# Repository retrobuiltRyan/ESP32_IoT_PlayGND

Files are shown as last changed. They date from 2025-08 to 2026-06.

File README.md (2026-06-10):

# ESP32_IoT_PlayGND
Internet of Things + MQTT sensor, input, actuator, motor drive learning board. Can be powered with a power drill battery for immediate remote deployment and sensor monitoring.

Learning Goal: Quick start "how to" develop and build your own IIoT solution with scale and affordability in mind using off-the-shelf hardware and lightweight software.

# Hardware Rev 1.0

| Category | Components |
|---|---|
| **Microcontroller** | ESP32-WROOM-32 |
| **Sensors/Input** | - Temperature & Humidity (SHT45) <br> - Voltage, Current, Power (INA260) <br> - Pushbutton (x4) <br> - Rotary Encoder |
| **Actuators** | - Relay (10A, 277VAC, 30VDC) <br> - DRV8871 (DC Motor Drive) <br> - A4988 (Stepper Motor Drive) <br> - 4 CH Servo (PCA9685) |
| **Output** | - RGB LED (x4) <br> - OLED (128x64 pixel) <br> - Buzzer |

IoT PlayGND pic
3D render

ESP-WROOM-32 ESP32: https://www.amazon.com/gp/product/B0D8Q8XFRK/ <br>
USB Drivers for FTDI chips https://docs.espressif.com/projects/esp-idf/en/stable/esp32/get-started/establish-serial-connection.html

BoM
## Bill of Materials (BOM)
| Reference | Value | Qty | DigiKey P/N | Adafruit P/N | AliExpress / Amazon Link |
|---|---|-----|---|---|---|
| BZ1 | Buzzer_5V | 1 | 445-2525-1-ND | | |
| C3, C4, C7 | 0.1uF 50V | 3 | 1276-1068-1-ND | | |
| C10, C11 | 0.22uF 50V CER | 2 | 445-2283-1-ND | | |
| C12, C13, C14 | 22uF 50V | 3 | 399-11438-1-ND | | |
| D2 | D | 1 | S5AC-FDICT-ND | | |
| D3, D6, D7, D8 | WS2812B | 4 |1568-16347CT-ND | |[Aliexpress Link](https://www.aliexpress.us/item/3256802466699315.html) |
| D5, D9, D11, D13 | LED, Green | 3 |1080-1419-1-ND | | |
| D10 | LED Red, 5mm | 1 | EALP05RDHRA2-ND | | |
| D12 | SMF15A | 1 | SMF15A-E3-08CT-ND | | |
| D14 | 1N4148W | 1 | 4878-1N4148WCT-ND | | |
| J3 | ServoPort_04 | 1 | S1012EC-40-ND | | |
| J5, J8 | Screw_Terminal_2_P3.50mm| 2 | 732-2747-ND | | |
| J7 | PINHD_2x3_Male | 1 | S1012EC-40-ND | | |
| J15 | Screw_Terminal_3_P5.00mm| 1 | 277-1578-ND | | |
| K1 | G5Q-1 | 1 | Z2929-ND | | |
| Q1 | MOSFET P-CH 30V 25A TO252| 1  | 785-1106-1-ND | | |
| Q2, Q3 | MMBT2222A | 2 | MMBT2222ATPMSCT-ND | | |
| R1, R2, R8, R22, R25, R26, R27, R28, R30, R34, R35, R36, R37, R38 | 10K | 14  | 311-10.0KFRCT-ND | | |
| R3, R4, R5, R6, R7, R9, R16, R23 | 220 | 8 | 311-220FRCT-ND | | |
| R17, R21, R31 | 330 | 3 | 311-330FRCT-ND | | |
| R18, R19, R20, R32 | 1K | 4 | 311-1.00KFRCT-ND | | |
| R33 | 100k | 1 | 311-100KFRCT-ND | | |
| S1 | SPDT Switch | 1 | EG5617-ND | | |
| SW1, SW2, SW3, SW4 | Push_Button | 4 | 2223-TS02-66-60-BK-160-LCR-D-ND | | |
| SW6 | RotaryEncoder_Switch_MP | 1 | PEC11R-4220F-S0024-ND | | |
| U3 | PCA9685PW | 1 | 568-11925-1-ND | | |
| U4 | SHT45 | 1 | | 6174 | |
| U7 | A4988 | 1 | | 6109 | |
| U8 | INA260 | 1 | | 4226 | |
| U14 | MAX40200AUK | 1 | 175-MAX40203AUK+TCT-ND | | |
| U15 | L7805 | 1 | 497-7255-1-ND | | |
| U18, U19 | MP1584 | 2 | | | [AliExpress Link](https://www.aliexpress.us/item/3256806890547813.html) |
| U21 | ESP32 | 1 | | | [Amazon Link](https://www.amazon.com/gp/product/B0D8Q8XFRK/) _(beware pinout)_ |

## Misc 
Try calling these in a desktop web browser for weather forecast in string format:

*main call*
https://api.weather.gov/points/40.4406,-79.9959

*hourly forecast call*
https://api.weather.gov/gridpoints/PBZ/78,66/forecast/hourly

*weekly forecast*
https://api.weather.gov/gridpoints/PBZ/78,66/forecast

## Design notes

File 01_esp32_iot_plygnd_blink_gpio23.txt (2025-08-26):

//01_esp32_iot_plygnd_blink_gpio23

const int LED = 23; // the physical 5mm LED is wired to GPIO 23
// the setup function runs once when you press reset or power the board
void setup() {
  pinMode(LED, OUTPUT); // initialize digital pin LED as an output.
}

// the loop function runs over and over again forever
void loop() {
  digitalWrite(LED, HIGH);  // turn the LED on (HIGH is the voltage level)
  delay(1000);                      // wait for a second
  digitalWrite(LED, LOW);   // turn the LED off by making the voltage LOW
  delay(1000);                      // wait for a second
}

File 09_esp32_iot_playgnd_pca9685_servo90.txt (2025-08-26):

//09_esp32_iot_playgnd_pca9685_servo90

#include <Wire.h>
#include <Adafruit_PWMServoDriver.h>

Adafruit_PWMServoDriver pwm = Adafruit_PWMServoDriver();  // Default I2C address 0x40

// Servo pulse range for Tower Pro SG90 (approximate)
#define SERVOMIN  150   // ~500 microseconds
#define SERVOMAX  600   // ~2400 microseconds
#define SERVO_FREQ 50   // Standard analog servo frequency (50Hz)

void setup() {
  Serial.begin(115200);
  Serial.println("Tower Pro SG90 Servo Test with PCA9685");

  pwm.begin();
  pwm.setOscillatorFrequency(27000000);  // Recommended for accuracy
  pwm.setPWMFreq(SERVO_FREQ);            // Must be set correctly

  delay(10);  // Small delay after initializing
}

void loop() {
  int servoChannel = 0;  // Using channel 0 on PCA9685

  // Sweep from minimum to maximum
  for (uint16_t pulselen = SERVOMIN; pulselen <= SERVOMAX; pulselen += 5) {
    pwm.setPWM(servoChannel, 0, pulselen);
    delay(10);  // Smooth movement
  }

  delay(500);

  // Sweep back from maximum to minimum
  for (uint16_t pulselen = SERVOMAX; pulselen >= SERVOMIN; pulselen -= 5) {
    pwm.setPWM(servoChannel, 0, pulselen);
    delay(10);
  }

  delay(500);
}

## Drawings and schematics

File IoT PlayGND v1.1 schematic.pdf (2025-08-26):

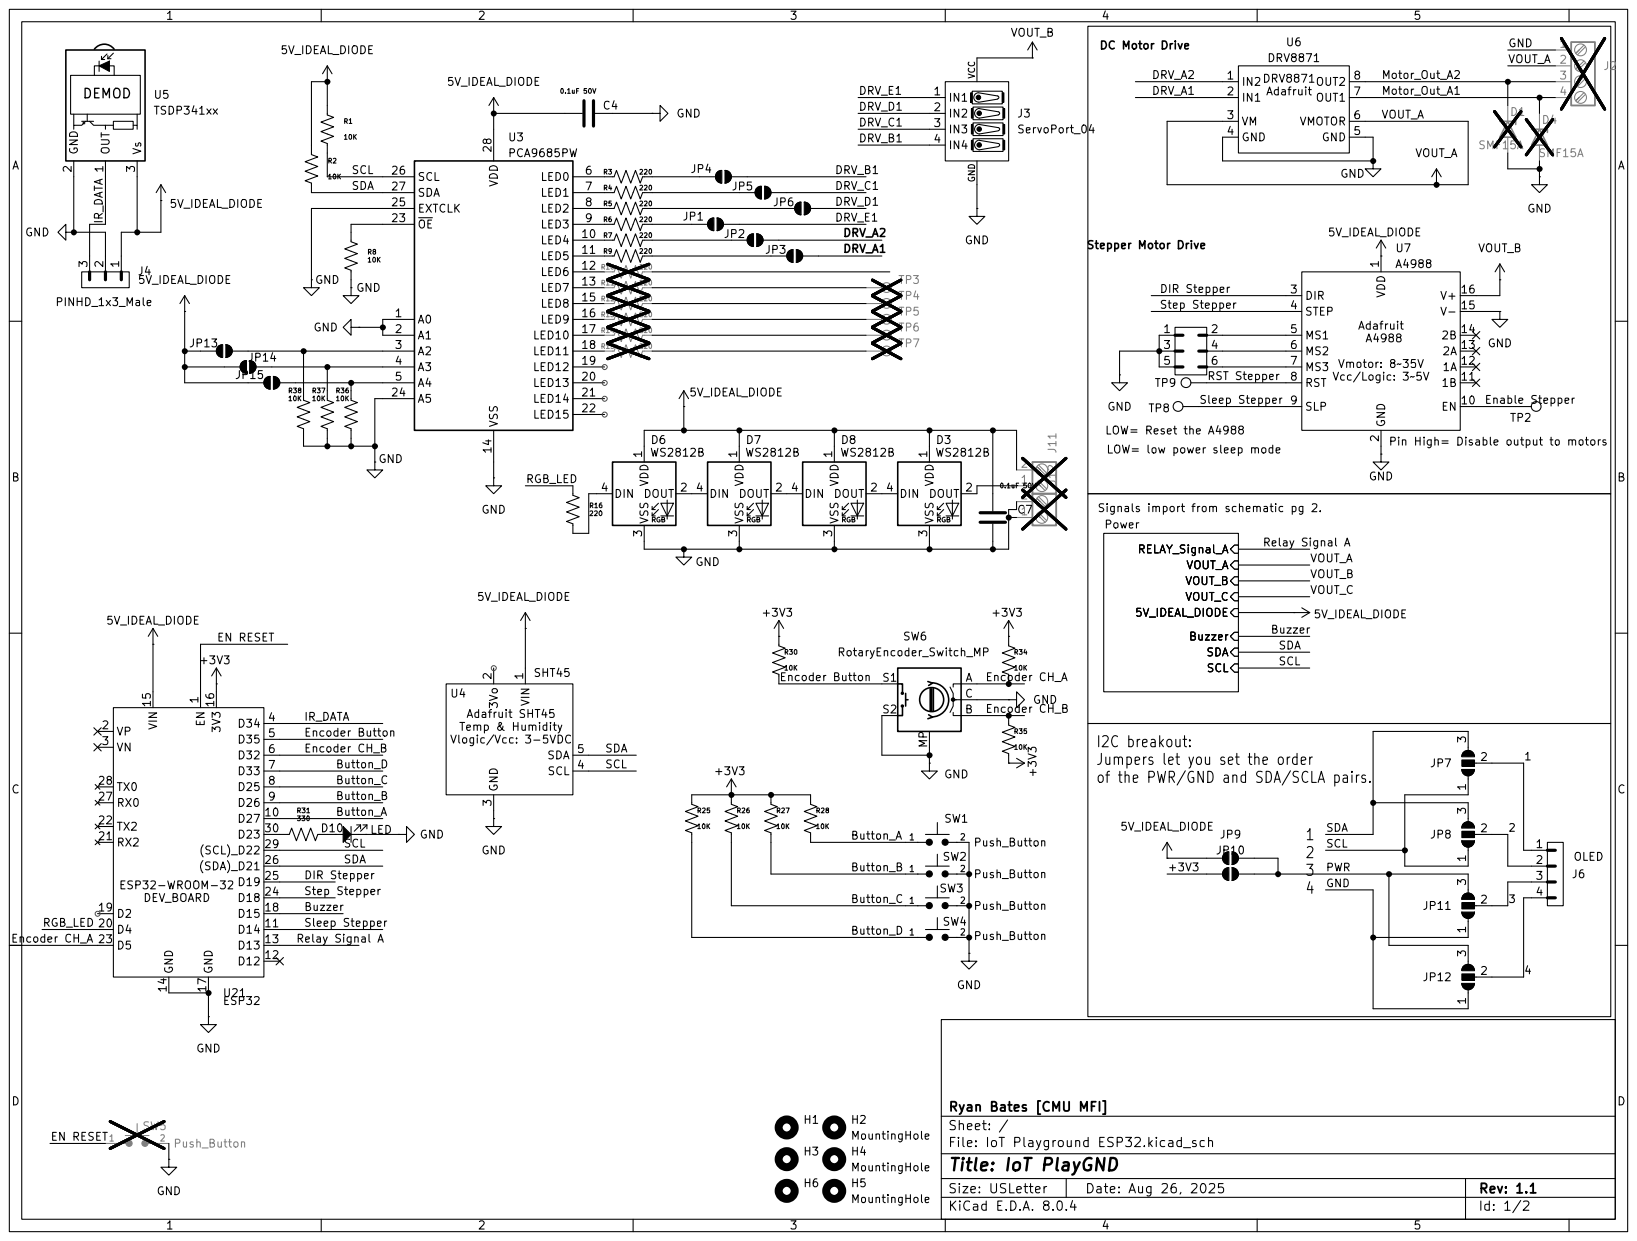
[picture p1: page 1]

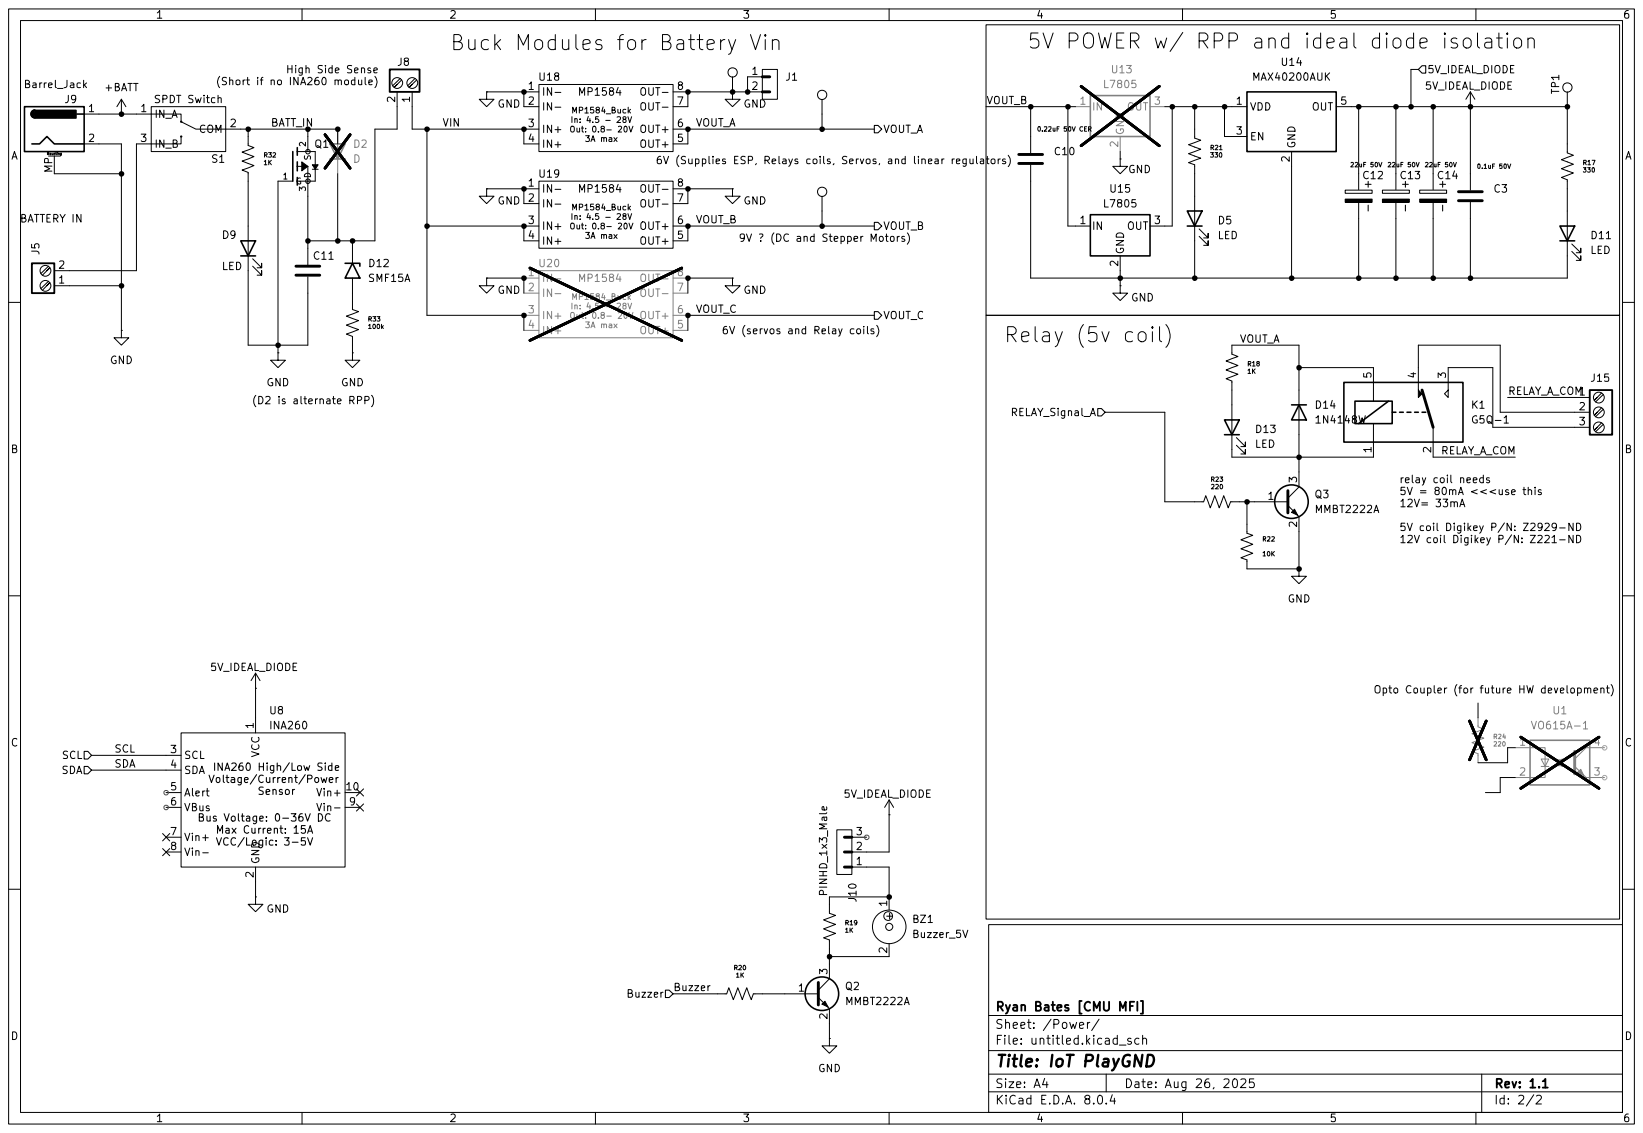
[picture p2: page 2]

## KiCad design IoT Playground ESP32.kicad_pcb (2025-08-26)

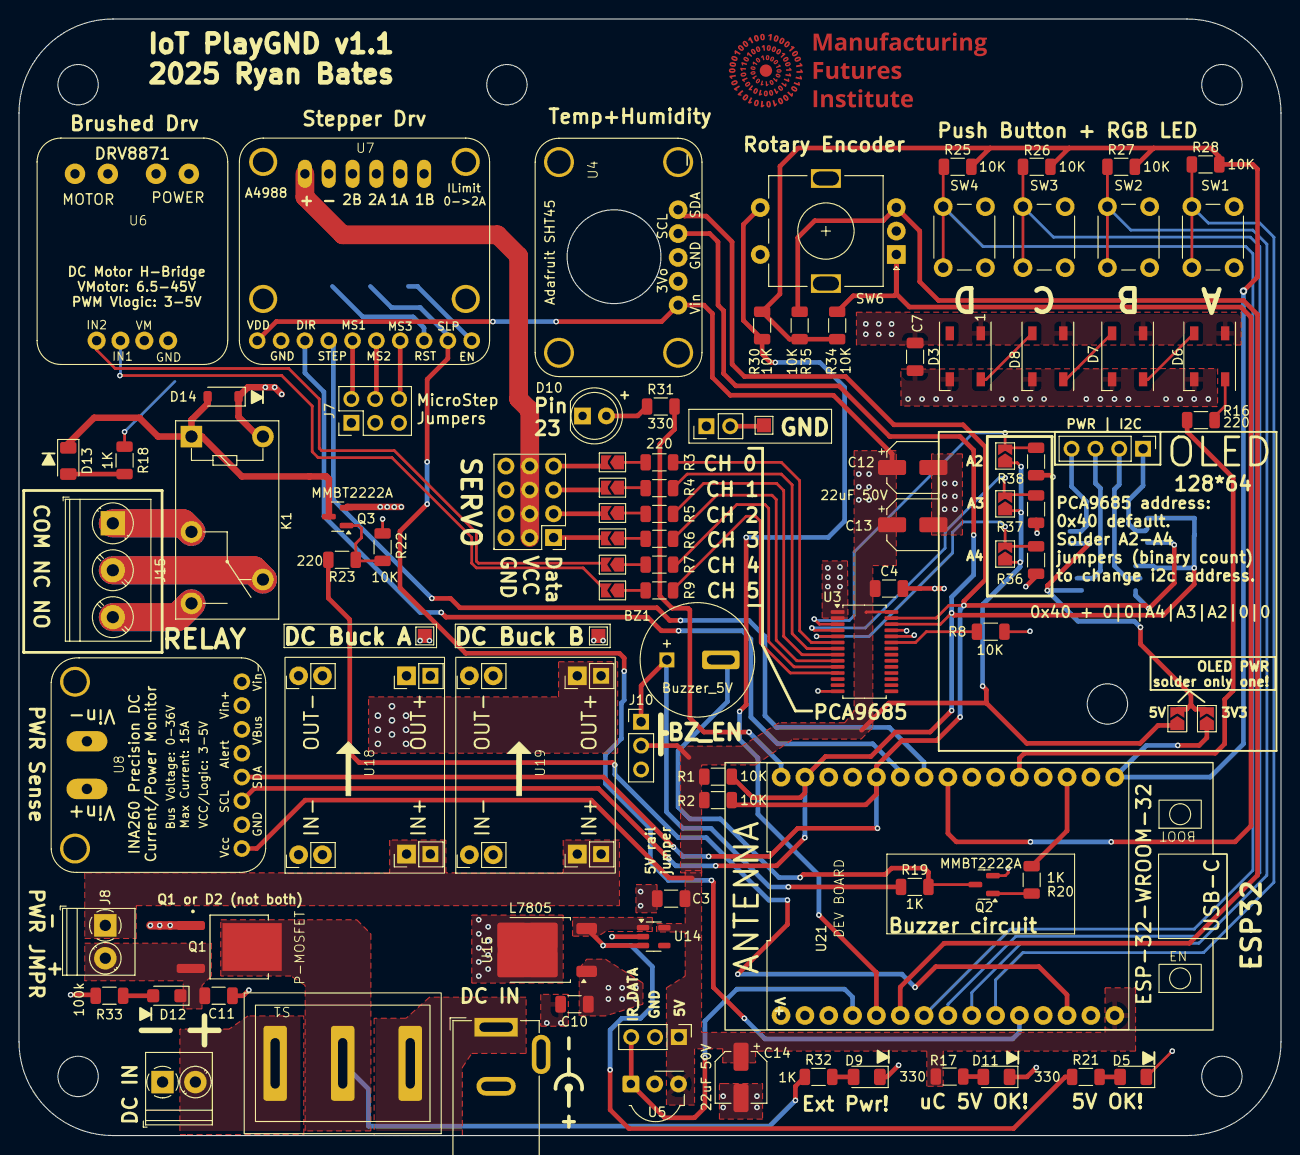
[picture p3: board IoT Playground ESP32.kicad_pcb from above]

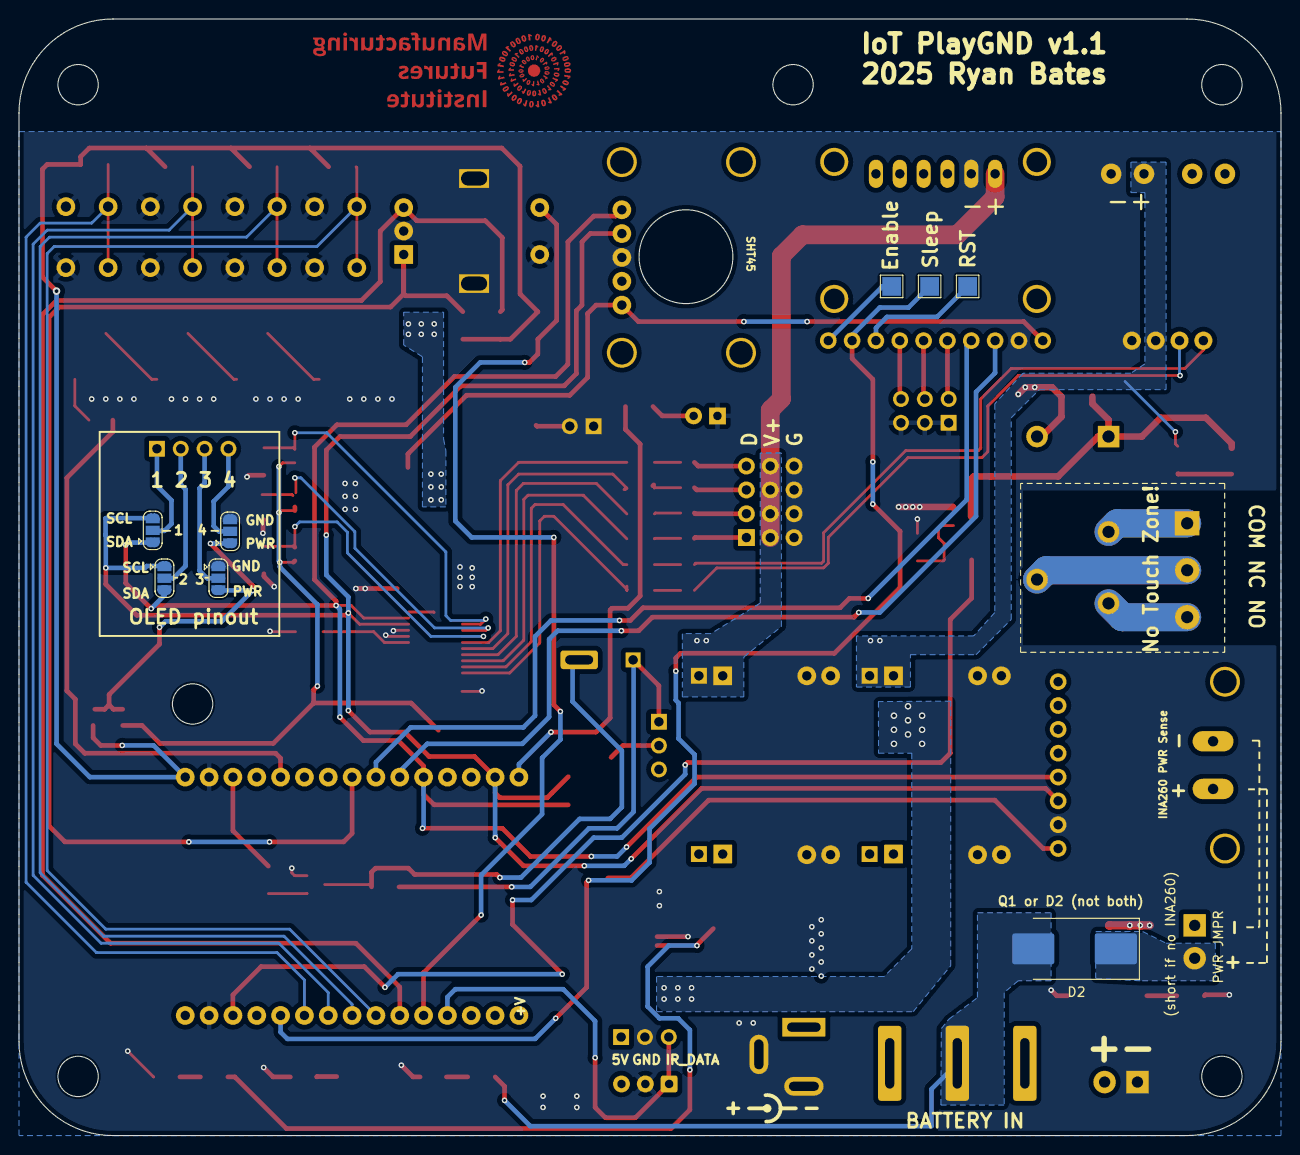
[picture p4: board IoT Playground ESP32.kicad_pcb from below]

Board: 2 copper layers, 134.5 x 119.0 mm, 109 parts (8 on the bottom side), 78 nets.

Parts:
BZ1: Buzzer_5V; MagneticBuzzer_ProSignal_ABT-410-RC
C3, C4, C7: 0.1uF 50V; C_1206_3216Metric
C10, C11: 0.22uF 50V CER; C_1206_3216Metric
C12, C13, C14: 22uF 50V; CP_Elec_5x5.3
D2: D; D_SMC_Handsoldering
D3, D6, D7, D8: WS2812B; LED_WS2812B_PLCC4_5.0x5.0mm_P3.2mm
D5, D9, D11, D13: LED; LED_1206_3216Metric
D10: LED; LED_D5.0mm
D12: SMF15A; D_SMF
D14: 1N4148W; D_SOD-123
H1, H2, H3, H4, H5, H6: MountingHole; MountingHole_4.3mm_M4
J1: PINHD_1x2_Male; PinHeader_1x02_P2.54mm_Vertical
J3: ServoPort_04; ServoPort_04_Vertical
J4, J10: PINHD_1x3_Male; PinHeader_1x03_P2.54mm_Vertical
J5, J8: Screw_Terminal_2_P3.50mm; TerminalBlock_Phoenix_PT-1,5-2-3.5-H_1x02_P3.50mm_Horizontal
J6: PINHD_1x4_Male; PinHeader_1x04_P2.54mm_Vertical
J7: PINHD_2x3_Male; PinHeader_2x03_P2.54mm_Vertical
J9: Barrel_Jack; BarrelJack_GCT_DCJ200-10-A_Horizontal
J15: Screw_Terminal_3_P5.00mm; TerminalBlock_Phoenix_PT-1,5-3-5.0-H_1x03_P5.00mm_Horizontal
JP1, JP2, JP3, JP4, JP5, JP6, JP9, JP10, JP13, JP14, JP15: SolderJumper_2_Open; SolderJumper-2_P1.3mm_Open_TrianglePad1.0x1.5mm
JP7, JP8, JP11, JP12: SolderJumper_3_Open; SolderJumper-3_P1.3mm_Open_RoundedPad1.0x1.5mm
K1: G5Q-1; Relay_SPDT_Omron-G5Q-1
Q1: MOSFET P-CH 30V 25A TO252; MOSFET_P-CH_30V_25A_TO252
Q2, Q3: MMBT2222A; SOT-23
R1, R2, R8, R22, R25, R26, R27, R28, R30, R34, R35, R36, R37, R38: 10K; R_1206_3216Metric
R3, R4, R5, R6, R7, R9, R16, R23: 220; R_1206_3216Metric
R17, R21, R31: 330; R_1206_3216Metric
R18, R19, R20, R32: 1K; R_1206_3216Metric
R33: 100k; R_1206_3216Metric
S1: SPDT Switch; SPDT_ Rocker_Switch
SW1, SW2, SW3, SW4: Push_Button; SW_PUSH_6mm
SW6: RotaryEncoder_Switch_MP; RotaryEncoder_Alps_EC11E-Switch_Vertical_H20mm
TP2, TP8, TP9: TestPoint; TestPoint_Pad_2.0x2.0mm
TP10, TP11, TP12: TestPoint; TestPoint_Pad_1.5x1.5mm
U3: PCA9685PW; TSSOP-28_4.4x9.7mm_P0.65mm
U4: SHT45; Adafruit SHT45
U5: TSDP341xx; Vishay_MOLD-3Pin
U6: DRV8871; DRV8871_Adafruit
U7: A4988; Adafruit A4988
U8: INA260; INA260_Adafruit
U14: MAX40200AUK; SOT-23-5
U15: L7805; TO-252-2
U18, U19: MP1584
U21: ESP32; ESP32-WROOM-32_DEV_BOARD

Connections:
5V_IDEAL_DIODE: C3.1, C4.1, C7.1, C12.1, C13.1, C14.1, D3.1 (VDD), D6.1 (VDD), D7.1 (VDD), D8.1 (VDD), J4.1, J10.2, JP9.1 (A), JP13.1 (A), JP14.1 (A), JP15.1 (A), R1.2, R2.2, R17.1, U3.28 (VDD), U4.1 (VIN), U5.3 (Vs), U7.1 (VDD), U8.1 (VCC), U14.5 (OUT), U21.15 (VIN)
+3V3: JP10.1 (A), R25.2, R26.2, R27.2, R28.2, R30.2, R34.2, R35.1, U21.16 (3V3)
+BATT: J9.1, S1.1 (IN_A)
/1: J6.1, JP7.2 (C)
/2: J6.2, JP8.2 (C)
/3: J6.3, JP11.2 (C)
/4: J6.4, JP12.2 (C)
/Button_A: R28.1, SW1.1, U21.10 (D27)
/Button_B: R27.1, SW2.1, U21.9 (D26)
/Button_C: R26.1, SW3.1, U21.8 (D25)
/Button_D: R25.1, SW4.1, U21.7 (D33)
/Buzzer: R20.1, U21.18 (D15)
/DIR Stepper: U7.3 (DIR), U21.25 (D19)
/DRV_A1: JP3.2 (B), U6.2 (IN1)
/DRV_A2: JP2.2 (B), U6.1 (IN2)
/DRV_B1: J3.4 (IN4), JP4.2 (B)
/DRV_C1: J3.3 (IN3), JP5.2 (B)
/DRV_D1: J3.2 (IN2), JP6.2 (B)
/DRV_E1: J3.1 (IN1), JP1.2 (B)
/Enable Stepper: TP2.1, U7.10 (EN)
/Encoder Button: R30.1, SW6.S1, U21.5 (D35)
/Encoder CH_A: R34.1, SW6.A, U21.23 (D5)
/Encoder CH_B: R35.2, SW6.B, U21.6 (D32)
/IR_DATA: J4.3, U5.1 (OUT), U21.4 (D34)
/PWR: JP9.2 (B), JP10.2 (B), JP11.3 (B), JP12.3 (B)
/Power/BATT_IN: D2.2 (A), Q1.2 (S), R32.1, S1.2 (COM)
/Power/RELAY_A_COM: J15.1, K1.2
/Power/VIN: J8.1, U18.3 (IN+), U18.4 (IN+), U19.3 (IN+), U19.4 (IN+)
/RGB_LED: R16.2, U21.20 (D4)
/RST Stepper: TP9.1, U7.8 (RST)
/Relay Signal A: R23.2, U21.13 (D13)
/SCL: JP7.1 (A), JP8.1 (A), R1.1, U3.26 (SCL), U4.4 (SCL), U8.3 (SCL), U21.29 ((SCL)_D22)
/SDA: JP7.3 (B), JP8.3 (B), R2.1, U3.27 (SDA), U4.5 (SDA), U8.4 (SDA), U21.26 ((SDA)_D21)
/Sleep Stepper: TP8.1, U7.9 (SLP), U21.11 (D14)
/Step Stepper: U7.4 (STEP), U21.24 (D18)
GND: C3.2, C4.2, C7.2, C10.2, C11.2, C12.2, C13.2, C14.2, D3.3 (VSS), D5.1 (K), D6.3 (VSS), D7.3 (VSS), D8.3 (VSS), D9.1 (K), D10.1, D11.1 (K), J1.1, J1.2, J3.GND, J4.2, J5.1, J7.1, J7.3, J7.5, J9.2, J9.MP (MountPin), JP11.1 (A), JP12.1 (A), Q1.1 (G), Q2.2 (E), Q3.2 (E), R8.2, R22.1, R33.2, R36.2, R37.2, R38.2, SW1.2, SW2.2, SW3.2, SW4.2, SW6.C, SW6.MP, SW6.S2, TP12.1, U3.1 (A0), U3.2 (A1), U3.14 (VSS), U3.24 (A5), U3.25 (EXTCLK), U4.3 (GND), U5.2 (GND), U6.4 (GND), U6.5 (GND), U7.2 (GND), U7.15 (V-), U8.2 (GND), U14.2 (GND), U15.2 (GND), U18.1 (IN-), U18.2 (IN-), U18.7 (OUT-), U18.8 (OUT-), U19.1 (IN-), U19.2 (IN-), U19.7 (OUT-), U19.8 (OUT-), U21.14 (GND), U21.17 (GND)
unnamed: BZ1.1, J10.1, R19.1
unnamed: D3.4 (DIN), D8.2 (DOUT)
unnamed: D5.2 (A), R21.2
unnamed: D6.4 (DIN), R16.1
unnamed: D6.2 (DOUT), D7.4 (DIN)
unnamed: D7.2 (DOUT), D8.4 (DIN)
unnamed: D9.2 (A), R32.2
unnamed: D10.2, R31.1
unnamed: D11.2 (A), R17.2
unnamed: C11.1, D2.1 (K), D12.1 (A1), J8.2, Q1.3 (D)
unnamed: D12.2 (A2), R33.1
unnamed: D13.2 (A), R18.2
unnamed: D13.1 (K), D14.2 (A), K1.1, Q3.3 (C)
unnamed: J15.2, K1.4
unnamed: J15.3, K1.3
unnamed: JP1.1 (A), R6.1
unnamed: JP2.1 (A), R7.1
unnamed: JP3.1 (A), R9.1
unnamed: JP4.1 (A), R3.1
unnamed: JP5.1 (A), R4.1
unnamed: JP6.1 (A), R5.1
unnamed: JP13.2 (B), R38.1, U3.3 (A2)
unnamed: JP14.2 (B), R37.1, U3.4 (A3)
unnamed: JP15.2 (B), R36.1, U3.5 (A4)
unnamed: Q2.1 (B), R20.2
unnamed: BZ1.2, Q2.3 (C), R19.2
unnamed: Q3.1 (B), R22.2, R23.1
unnamed: J5.2, S1.3 (IN_B)
unnamed: R3.2, U3.6 (LED0)
unnamed: R4.2, U3.7 (LED1)
unnamed: R5.2, U3.8 (LED2)
unnamed: R6.2, U3.9 (LED3)
unnamed: R7.2, U3.10 (LED4)
unnamed: R9.2, U3.11 (LED5)
unnamed: R8.1, U3.23 (~OE)
unnamed: J7.2, U7.5 (MS1)
unnamed: J7.4, U7.6 (MS2)
unnamed: J7.6, U7.7 (MS3)
unnamed: R21.1, U14.1 (VDD), U14.3 (EN), U15.3 (OUT)
unnamed: R31.2, U21.30 (D23)
VOUT_A: D14.1 (K), K1.5, R18.1, TP10.1, U6.3 (VM), U6.6 (VMOTOR), U18.5 (OUT+), U18.6 (OUT+)
VOUT_B: C10.1, J3.VCC, TP11.1, U7.16 (V+), U15.1 (IN), U19.5 (OUT+), U19.6 (OUT+)

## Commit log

2025-07-30 Example Code
    Arduino IDE 2.0+
2025-07-30 Design Files
    kiCAD
    [IoT Playground ESP32.kicad_pcb, IoT Playground ESP32.kicad_sch, untitled.kicad_sch]
2025-08-26 Update 01) ESP32 IoT_PlayGND Blink GPIO23.txt
    fix led variable
2025-08-26 Update 14) ESP32 IoT_PlayGND MQTT w 1.3in OLED.txt
    wifi credentials change
2025-08-26 Schematic v1.1 (printable pdf)
2025-08-26 kicad design files v1
    untitled is schematic page 2/2
    [IoT Playground ESP32.kicad_pcb, IoT Playground ESP32.kicad_sch, untitled.kicad_sch]
2025-09-11 Update README.md
    led PN
2026-06-10 Update README.md
    ftdi driver link
